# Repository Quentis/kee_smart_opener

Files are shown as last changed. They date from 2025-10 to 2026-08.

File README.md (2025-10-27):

# RAIL - SoC Empty

## Introduction

The Empty Example application is a boilerplate example which doesn't do anything
except initializes RAIL to support a Single PHY radio configuration. Also, this
example defines an empty radio event handler. These are the necessary parts what
every RAIL-based application requires.

## Prerequisites

The Empty Example application is supported on every EFR32 generations and
families that support proprietary software.

## Getting Started

Unlike the most of the available example applications in RAIL SDK, the Empty
Example does not define Command Line Interface nor does it support standard VCOM
printing or any other peripheral (LEDs/Button instances) by default.

Compile the project and download the application to a radio board. An unmodified
Empty Example shouldn't do any special:

- the radio is in idle state, while
- the MCU is running in an empty loop.

You might measure the current consumption (see the device's datasheet for the
expected active mode consumption) or debug the target device to make sure that
the example has been downloaded correctly to your device.

----

You can make the example energy friendly as simple as installing the `Power
Manager` component. Doing that the device will go to EM2 state after
initialization.

----

Adding basic packet TX/RX capabilities you might install the `Simple RAIL
Tx`/`Simple RAIL Rx` components.

## Peripherals

You can add LED and Button instances in the `Software Components` window.

To enable CLI interface you should install the `Command Line Interface (CLI)`
component. Make sure you satisfied the requirements by adding one of the `IO
Stream` dependency component, otherwise project generation will fail. If you are
working with a Silicon Labs development kit you should also ensure that the
Virtual COM port is enabled in the `Board Control` component in order to turn on
the serial bridge on the mainboard.

## Notes

> The application is designed in a way, that it can be run on an OS. You can add
> any RTOS support for this application in the `Software Components` window.
> Currently `MicriumOS` and `FreeRTOS` is supported.

## Conclusion

The `RAIL - SoC Empty` application sets up the absolute minimum to
start developing an application based on RAIL. If you want to test the basic
radio operation (packet transmission and reception) it is advised to create
`RAIL - SoC Simple TRX`.

## Resources

- [RAIL Tutorial
  Series](https://community.silabs.com/s/article/rail-tutorial-series?language=en_US):
  it is advised to read through the `Studio v5 series` first to familiarize the
  basics of packet transmission and reception.

## Report Bugs & Get Support

You are always encouraged and welcome to report any issues you found to us via
[Silicon Labs
Community](https://community.silabs.com/s/topic/0TO1M000000qHaKWAU/proprietary?language=en_US).

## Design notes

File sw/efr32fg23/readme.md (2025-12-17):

# RAIL - SoC Empty

## Introduction

The Empty Example application is a boilerplate example which doesn't do anything
except initializes RAIL to support a Single PHY radio configuration. Also, this
example defines an empty radio event handler. These are the necessary parts what
every RAIL-based application requires.

## Prerequisites

The Empty Example application is supported on every EFR32 generations and
families that support proprietary software.

## Getting Started

Unlike the most of the available example applications in RAIL SDK, the Empty
Example does not define Command Line Interface nor does it support standard VCOM
printing or any other peripheral (LEDs/Button instances) by default.

Compile the project and download the application to a radio board. An unmodified
Empty Example shouldn't do any special:

- the radio is in idle state, while
- the MCU is running in an empty loop.

You might measure the current consumption (see the device's datasheet for the
expected active mode consumption) or debug the target device to make sure that
the example has been downloaded correctly to your device.

----

You can make the example energy friendly as simple as installing the `Power
Manager` component. Doing that the device will go to EM2 state after
initialization.

----

Adding basic packet TX/RX capabilities you might install the `Simple RAIL
Tx`/`Simple RAIL Rx` components.

## Peripherals

You can add LED and Button instances in the `Software Components` window.

To enable CLI interface you should install the `Command Line Interface (CLI)`
component. Make sure you satisfied the requirements by adding one of the `IO
Stream` dependency component, otherwise project generation will fail. If you are
working with a Silicon Labs development kit you should also ensure that the
Virtual COM port is enabled in the `Board Control` component in order to turn on
the serial bridge on the mainboard.

## Notes

> The application is designed in a way, that it can be run on an OS. You can add
> any RTOS support for this application in the `Software Components` window.
> Currently `MicriumOS` and `FreeRTOS` is supported.

## Conclusion

The `RAIL - SoC Empty` application sets up the absolute minimum to
start developing an application based on RAIL. If you want to test the basic
radio operation (packet transmission and reception) it is advised to create
`RAIL - SoC Simple TRX`.

## Resources

- [RAIL Tutorial
  Series](https://community.silabs.com/s/article/rail-tutorial-series?language=en_US):
  it is advised to read through the `Studio v5 series` first to familiarize the
  basics of packet transmission and reception.

## Report Bugs & Get Support

You are always encouraged and welcome to report any issues you found to us via
[Silicon Labs
Community](https://community.silabs.com/s/topic/0TO1M000000qHaKWAU/proprietary?language=en_US).

## Startup

HFXO Startup Time: 178us

Reference: EFR32FG23 Wireless SoC Family Data Sheet

## Retrospective

I found these functional, non-functional, DX issues during development.

Some components requires power_manager component. I suppose because power manager provides some types for baremetal.
This is problematic because you may have a project which requires no power management then adding e.g. button press component the whole project starts to use power management however button press doesn't really need power manager for its functionality. This power management requirement is even more unnecessary for RTOS project in some cases because is_ok_to_sleep isn't needed in RTOS projects.

Missing comma in macro definition in app_log:
// ARRAY DUMP
#define app_log_array_dump_level(level, p_data, len, format) \
  app_log_array_dump_level_s(level,                          \
                             APP_LOG_ARRAY_DUMP_SEPARATOR    \
                             p_data,                         \
                             len,                            \
                             format)

## Measurements

**rtl_433-rtlsdr -R help**
[131]  Microchip HCS200/HCS300 KeeLoq Hopping Encoder based remotes

**rtl_433-rtlsdr -f 433.92M -Y level=-80 -s 2048k -g 0 -R 131 -A**

Detected OOK package    2025-12-17 14:02:14
_ _ _ _ _ _ _ _ _ _ _ _ _ _ _ _ _ _ _ _ _ _ _ _ _ _ _ _ _ _ _ _ _ _ _ _ _ _ _ _ _ _ _ _ _ _ _ _ _ _ _ _ _ _ _ _ _ _ _ _ _ _ _ _ _ _ _ _ _ _ _ _ _ _ _ _ _ _ _ _ _ _ _ _ _ _ _ _ _ _ _ _ _ _ _ _ _ _ _ _ _ _ _ _
time      : 2025-12-17 14:02:14
model     : Microchip-HCS200                       id        : 0095D63
Battery   : 1            Button    : 1             Learn mode: 0             Repeat    : 0             encrypted : 46029991
Analyzing pulses...
Total count:   78,  width: 92.01 ms             (188429 S)
Pulse width distribution:
 [ 0] count:   35,  width:  404 us [403;406]    ( 827 S)
 [ 1] count:   43,  width:  803 us [803;804]    (1645 S)
Gap width distribution:
 [ 0] count:   53,  width:  396 us [396;397]    ( 811 S)
 [ 1] count:    1,  width: 3997 us [3997;3997]  (8185 S)
 [ 2] count:   23,  width:  796 us [795;797]    (1630 S)
Pulse period distribution:
 [ 0] count:   11,  width:  800 us [799;801]    (1638 S)
 [ 1] count:    1,  width: 4400 us [4400;4400]  (9012 S)
 [ 2] count:   65,  width: 1200 us [1200;1200]  (2457 S)
Pulse timing distribution:
 [ 0] count:   88,  width:  399 us [396;406]    ( 817 S)
 [ 1] count:   66,  width:  801 us [795;804]    (1640 S)
 [ 2] count:    1,  width: 3997 us [3997;3997]  (8185 S)
 [ 3] count:    1,  width: 10000 us [10000;10000]       (20481 S)
Level estimates [high, low]:  15931,    472
RSSI: -0.1 dB SNR: 15.3 dB Noise: -15.4 dB
Frequency offsets [F1, F2]:   18614,      0     (+581.7 kHz, +0.0 kHz)
Guessing modulation: Pulse Width Modulation with multiple packets
view at https://triq.org/pdv/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
Attempting demodulation... short_width: 404, long_width: 803, reset_limit: 3997, sync_width: 0
Use a flex decoder with -X 'n=name,m=OOK_PWM,s=404,l=803,r=3997,g=798,t=160,y=0'
[pulse_slicer_pwm] Analyzer Device
codes     : {12}fff, {66}89994062c6ba90040

Detected OOK package    2025-12-17 14:04:35
_ _ _ _ _ _ _ _ _ _ _ _ _ _ _ _ _ _ _ _ _ _ _ _ _ _ _ _ _ _ _ _ _ _ _ _ _ _ _ _ _ _ _ _ _ _ _ _ _ _ _ _ _ _ _ _ _ _ _ _ _ _ _ _ _ _ _ _ _ _ _ _ _ _ _ _ _ _ _ _ _ _ _ _ _ _ _ _ _ _ _ _ _ _ _ _ _ _ _ _ _ _ _ _
time      : 2025-12-17 14:04:35
model     : Microchip-HCS200                       id        : 0095D63
Battery   : 1            Button    : 1             Learn mode: 0             Repeat    : 0             encrypted : 5DC7A207
Analyzing pulses...
Total count:   78,  width: 92.01 ms             (188428 S)
Pulse width distribution:
 [ 0] count:   40,  width:  403 us [403;405]    ( 826 S)
 [ 1] count:   38,  width:  804 us [803;805]    (1646 S)
Gap width distribution:
 [ 0] count:   48,  width:  396 us [396;397]    ( 811 S)
 [ 1] count:    1,  width: 3996 us [3996;3996]  (8184 S)
 [ 2] count:   28,  width:  796 us [795;797]    (1630 S)
Pulse period distribution:
 [ 0] count:   11,  width:  800 us [800;801]    (1638 S)
 [ 1] count:    1,  width: 4399 us [4399;4399]  (9010 S)
 [ 2] count:   65,  width: 1200 us [1199;1201]  (2457 S)
Pulse timing distribution:
 [ 0] count:   88,  width:  399 us [396;405]    ( 818 S)
 [ 1] count:   66,  width:  800 us [795;805]    (1639 S)
 [ 2] count:    1,  width: 3996 us [3996;3996]  (8184 S)
 [ 3] count:    1,  width: 10000 us [10000;10000]       (20481 S)
Level estimates [high, low]:  15726,    418
RSSI: -0.2 dB SNR: 15.8 dB Noise: -15.9 dB
Frequency offsets [F1, F2]:   17155,      0     (+536.1 kHz, +0.0 kHz)
Guessing modulation: Pulse Width Modulation with multiple packets
view at https://triq.org/pdv/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
Attempting demodulation... short_width: 403, long_width: 804, reset_limit: 3997, sync_width: 0
Use a flex decoder with -X 'n=name,m=OOK_PWM,s=403,l=804,r=3997,g=798,t=160,y=0'
[pulse_slicer_pwm] Analyzer Device
codes     : {12}fff, {66}e045e3bac6ba90040

Detected OOK package    2025-12-17 14:04:35
_ _ _ _ _ _ _ _ _ _ _ _ _ _ _ _ _ _ _ _ _ _ _ _ _ _ _ _ _ _ _ _ _ _ _ _ _ _ _ _ _ _ _ _ _ _ _ _ _ _ _ _ _ _ _ _ _ _ _ _ _ _ _ _ _ _ _ _ _ _ _ _ _ _ _ _ _ _ _ _ _ _ _ _ _ _ _ _ _ _ _ _ _ _ _ _ _ _ _ _ _ _ _ _
time      : 2025-12-17 14:04:35
model     : Microchip-HCS200                       id        : 0095D63
Battery   : 1            Button    : 1             Learn mode: 0             Repeat    : 1             encrypted : 5DC7A207
Analyzing pulses...
Total count:   78,  width: 91.61 ms             (187609 S)
Pulse width distribution:
 [ 0] count:   41,  width:  404 us [403;405]    ( 827 S)
 [ 1] count:   37,  width:  804 us [803;805]    (1646 S)
Gap width distribution:
 [ 0] count:   48,  width:  396 us [396;397]    ( 811 S)
 [ 1] count:    1,  width: 3996 us [3996;3996]  (8184 S)
 [ 2] count:   28,  width:  796 us [795;797]    (1630 S)
Pulse period distribution:
 [ 0] count:   11,  width:  800 us [800;801]    (1638 S)
 [ 1] count:    1,  width: 4400 us [4400;4400]  (9012 S)
 [ 2] count:   65,  width: 1200 us [1199;1201]  (2457 S)
Pulse timing distribution:
 [ 0] count:   89,  width:  399 us [396;405]    ( 818 S)
 [ 1] count:   65,  width:  800 us [795;805]    (1639 S)
 [ 2] count:    1,  width: 3996 us [3996;3996]  (8184 S)
 [ 3] count:    1,  width: 10000 us [10000;10000]       (20481 S)
Level estimates [high, low]:  15846,    479
RSSI: -0.1 dB SNR: 15.2 dB Noise: -15.3 dB
Frequency offsets [F1, F2]:   19862,      0     (+620.7 kHz, +0.0 kHz)
Guessing modulation: Pulse Width Modulation with multiple packets
view at https://triq.org/pdv/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
Attempting demodulation... short_width: 404, long_width: 804, reset_limit: 3997, sync_width: 0
Use a flex decoder with -X 'n=name,m=OOK_PWM,s=404,l=804,r=3997,g=797,t=160,y=0'
[pulse_slicer_pwm] Analyzer Device
codes     : {12}fff, {66}e045e3bac6ba90044

Detected OOK package    2025-12-17 14:04:35
_ _ _ _ _ _ _ _ _ _ _ _ _ _ _ _ _ _ _ _ _ _ _ _ _ _ _ _ _ _ _ _ _ _ _ _ _ _ _ _ _ _ _ _ _ _ _ _ _ _ _ _ _ _ _ _ _ _ _ _ _ _ _ _ _ _ _ _ _ _ _ _ _ _ _ _ _ _ _ _ _ _ _ _ _ _ _ _ _ _ _ _ _ _ _ _ _ _ _ _ _ _ _ _
time      : 2025-12-17 14:04:35
model     : Microchip-HCS200                       id        : 0095D63
Battery   : 1            Button    : 1             Learn mode: 0             Repeat    : 1             encrypted : 5DC7A207
Analyzing pulses...
Total count:   78,  width: 91.61 ms             (187610 S)
Pulse width distribution:
 [ 0] count:   41,  width:  404 us [403;405]    ( 827 S)
 [ 1] count:   37,  width:  804 us [803;805]    (1646 S)
Gap width distribution:
 [ 0] count:   48,  width:  396 us [396;397]    ( 811 S)
 [ 1] count:    1,  width: 3997 us [3997;3997]  (8185 S)
 [ 2] count:   28,  width:  796 us [795;797]    (1630 S)
Pulse period distribution:
 [ 0] count:   11,  width:  800 us [799;802]    (1638 S)
 [ 1] count:    1,  width: 4400 us [4400;4400]  (9012 S)
 [ 2] count:   65,  width: 1200 us [1199;1201]  (2457 S)
Pulse timing distribution:
 [ 0] count:   89,  width:  399 us [396;405]    ( 818 S)
 [ 1] count:   65,  width:  800 us [795;805]    (1639 S)
 [ 2] count:    1,  width: 3997 us [3997;3997]  (8185 S)
 [ 3] count:    1,  width: 10000 us [10000;10000]       (20481 S)
Level estimates [high, low]:  15923,    235
RSSI: -0.1 dB SNR: 18.3 dB Noise: -18.4 dB
Frequency offsets [F1, F2]:   19716,      0     (+616.1 kHz, +0.0 kHz)
Guessing modulation: Pulse Width Modulation with multiple packets
view at https://triq.org/pdv/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
Attempting demodulation... short_width: 404, long_width: 804, reset_limit: 3997, sync_width: 0
Use a flex decoder with -X 'n=name,m=OOK_PWM,s=404,l=804,r=3997,g=797,t=160,y=0'
[pulse_slicer_pwm] Analyzer Device
codes     : {12}fff, {66}e045e3bac6ba90044

Detected OOK package    2025-12-17 14:04:36
_ _ _ _ _ _ _ _ _ _ _ _ _ _ _ _ _ _ _ _ _ _ _ _ _ _ _ _ _ _ _ _ _ _ _ _ _ _ _ _ _ _ _ _ _ _ _ _ _ _ _ _ _ _ _ _ _ _ _ _ _ _ _ _ _ _ _ _ _ _ _ _ _ _ _ _ _ _ _ _ _ _ _ _ _ _ _ _ _ _ _ _ _ _ _ _ _ _ _ _ _ _ _ _
time      : 2025-12-17 14:04:36
model     : Microchip-HCS200                       id        : 0095D63
Battery   : 1            Button    : 1             Learn mode: 0             Repeat    : 1             encrypted : 5DC7A207
Analyzing pulses...
Total count:   78,  width: 91.61 ms             (187609 S)
Pulse width distribution:
 [ 0] count:   41,  width:  403 us [403;406]    ( 826 S)
 [ 1] count:   37,  width:  803 us [803;805]    (1645 S)
Gap width distribution:
 [ 0] count:   48,  width:  396 us [396;397]    ( 811 S)
 [ 1] count:    1,  width: 3997 us [3997;3997]  (8185 S)
 [ 2] count:   28,  width:  796 us [795;797]    (1630 S)
Pulse period distribution:
 [ 0] count:   11,  width:  800 us [800;802]    (1638 S)
 [ 1] count:    1,  width: 4400 us [4400;4400]  (9011 S)
 [ 2] count:   65,  width: 1200 us [1199;1201]  (2457 S)
Pulse timing distribution:
 [ 0] count:   89,  width:  399 us [396;406]    ( 818 S)
 [ 1] count:   65,  width:  800 us [795;805]    (1639 S)
 [ 2] count:    1,  width: 3997 us [3997;3997]  (8185 S)
 [ 3] count:    1,  width: 10000 us [10000;10000]       (20481 S)
Level estimates [high, low]:  15648,     77
RSSI: -0.2 dB SNR: 23.1 dB Noise: -23.3 dB
Frequency offsets [F1, F2]:   17343,      0     (+542.0 kHz, +0.0 kHz)
Guessing modulation: Pulse Width Modulation with multiple packets
view at https://triq.org/pdv/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
Attempting demodulation... short_width: 403, long_width: 803, reset_limit: 3997, sync_width: 0
Use a flex decoder with -X 'n=name,m=OOK_PWM,s=403,l=803,r=3997,g=797,t=160,y=0'
[pulse_slicer_pwm] Analyzer Device
codes     : {12}fff, {66}e045e3bac6ba90044

Detected OOK package    2025-12-17 14:04:36
_ _ _ _ _ _ _ _ _ _ _ _ _ _ _ _ _ _ _ _ _ _ _ _ _ _ _ _ _ _ _ _ _ _ _ _ _ _ _ _ _ _ _ _ _ _ _ _ _ _ _ _ _ _ _ _ _ _ _ _ _ _ _ _ _ _ _ _ _ _ _ _ _ _ _ _ _ _ _ _ _ _ _ _ _ _ _ _ _ _ _ _ _ _ _ _ _ _ _ _ _ _ _ _
time      : 2025-12-17 14:04:36
model     : Microchip-HCS200                       id        : 0095D63
Battery   : 1            Button    : 1             Learn mode: 0             Repeat    : 1             encrypted : 5DC7A207
Analyzing pulses...
Total count:   78,  width: 91.61 ms             (187608 S)
Pulse width distribution:
 [ 0] count:   41,  width:  403 us [402;406]    ( 826 S)
 [ 1] count:   37,  width:  803 us [802;804]    (1645 S)
Gap width distribution:
 [ 0] count:   48,  width:  396 us [396;397]    ( 812 S)
 [ 1] count:    1,  width: 3997 us [3997;3997]  (8186 S)
 [ 2] count:   28,  width:  796 us [795;797]    (1631 S)
Pulse period distribution:
 [ 0] count:   11,  width:  800 us [800;802]    (1638 S)
 [ 1] count:    1,  width: 4400 us [4400;4400]  (9011 S)
 [ 2] count:   65,  width: 1200 us [1199;1201]  (2457 S)
Pulse timing distribution:
 [ 0] count:   89,  width:  399 us [396;406]    ( 818 S)
 [ 1] count:   65,  width:  800 us [795;804]    (1639 S)
 [ 2] count:    1,  width: 3997 us [3997;3997]  (8186 S)
 [ 3] count:    1,  width: 10000 us [10000;10000]       (20481 S)
Level estimates [high, low]:  15731,     52
RSSI: -0.2 dB SNR: 24.8 dB Noise: -25.0 dB
Frequency offsets [F1, F2]:   17112,      0     (+534.8 kHz, +0.0 kHz)
Guessing modulation: Pulse Width Modulation with multiple packets
view at https://triq.org/pdv/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
Attempting demodulation... short_width: 403, long_width: 803, reset_limit: 3998, sync_width: 0
Use a flex decoder with -X 'n=name,m=OOK_PWM,s=403,l=803,r=3998,g=798,t=160,y=0'
[pulse_slicer_pwm] Analyzer Device
codes     : {12}fff, {66}e045e3bac6ba90044

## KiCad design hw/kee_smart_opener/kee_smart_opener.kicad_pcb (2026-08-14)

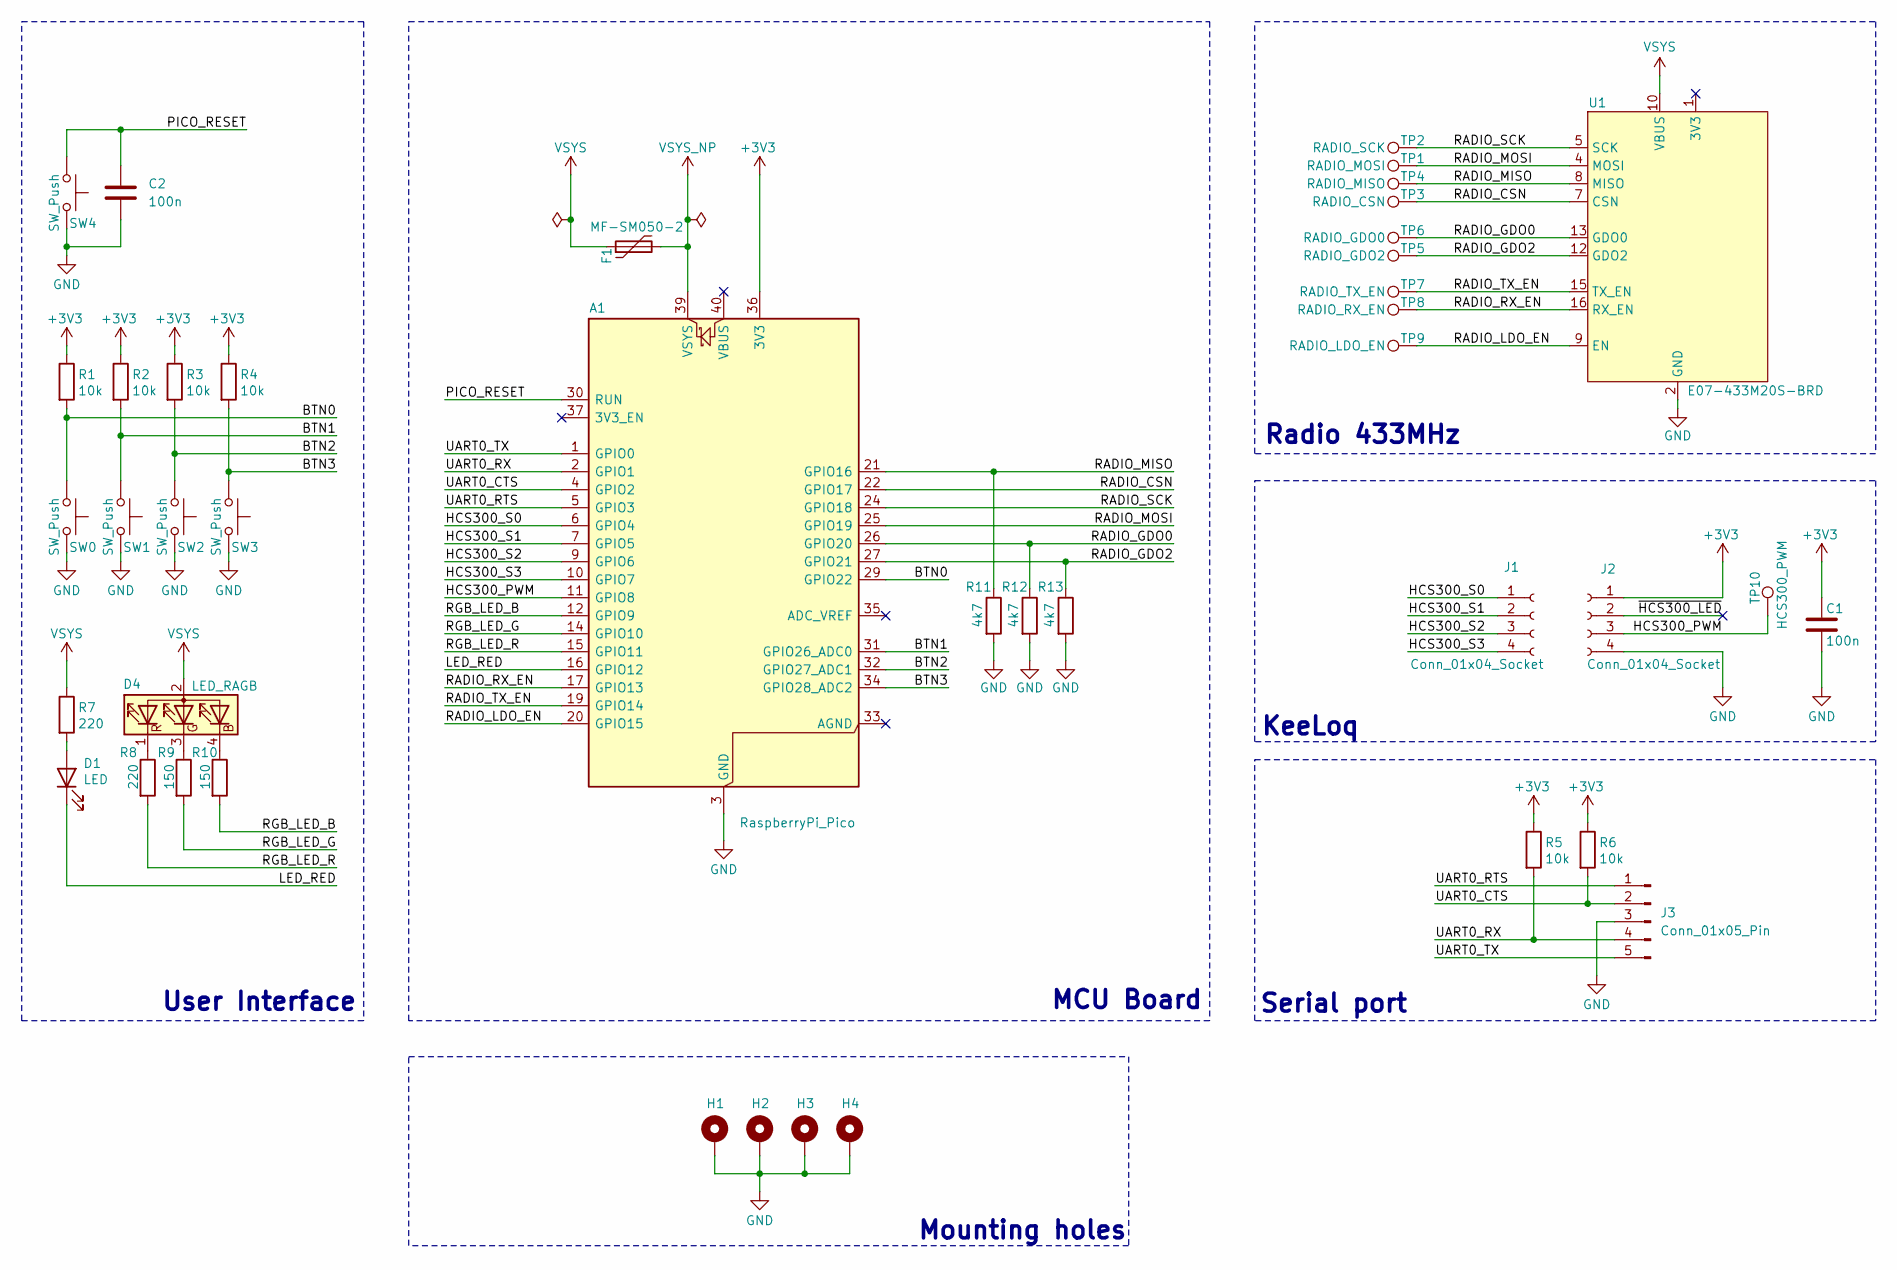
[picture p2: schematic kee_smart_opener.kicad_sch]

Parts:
A1: RaspberryPi_Pico; RaspberryPi_Pico_Common_THT
C1, C2: 100n; C_0603_1608Metric_Pad1.08x0.95mm_HandSolder
D1: LED; LED_D5.0mm
D4: LED_RAGB; LED_D5.0mm-4_RGB
F1: MF-SM050-2; Fuse_Bourns_MF-SM_7.98x5.44mm
H1, H2, H3, H4: MountingHole_Pad; MountingHole_3.5mm_Pad_Via
J1, J2: Conn_01x04_Socket; PinSocket_1x04_P2.54mm_Vertical
J3: Conn_01x05_Pin; PinHeader_1x05_P2.54mm_Horizontal
R1, R2, R3, R4, R5, R6: 10k; R_0603_1608Metric_Pad0.98x0.95mm_HandSolder
R7, R8: 220; R_0603_1608Metric_Pad0.98x0.95mm_HandSolder
R9, R10: 150; R_0603_1608Metric_Pad0.98x0.95mm_HandSolder
R11, R12, R13: 4k7; R_0603_1608Metric_Pad0.98x0.95mm_HandSolder
SW0, SW1, SW2, SW3, SW4: SW_Push; SW_B3F-3100
TP1: RADIO_MOSI; TestPoint_Pad_D1.5mm
TP2: RADIO_SCK; TestPoint_Pad_D1.5mm
TP3: RADIO_CSN; TestPoint_Pad_D1.5mm
TP4: RADIO_MISO; TestPoint_Pad_D1.5mm
TP5: RADIO_GDO2; TestPoint_Pad_D1.5mm
TP6: RADIO_GDO0; TestPoint_Pad_D1.5mm
TP7: RADIO_TX_EN; TestPoint_Pad_D1.5mm
TP8: RADIO_RX_EN; TestPoint_Pad_D1.5mm
TP9: RADIO_LDO_EN; TestPoint_Pad_D1.5mm
TP10: HCS300_PWM; TestPoint_Pad_D1.5mm
U1: E07-433M20S-BRD

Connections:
+3V3: A1.36 (3V3), C1.1, J2.1, R1.1, R2.1, R3.1, R4.1, R5.1, R6.1
/BTN0: A1.29 (GPIO22), R1.2, SW0.2
/BTN1: A1.31 (GPIO26_ADC0), R2.2, SW1.2
/BTN2: A1.32 (GPIO27_ADC1), R3.2, SW2.2
/BTN3: A1.34 (GPIO28_ADC2), R4.2, SW3.2
/HCS300_PWM: A1.11 (GPIO8), J2.3, TP10.1 (1_1)
/HCS300_S0: A1.6 (GPIO4), J1.1
/HCS300_S1: A1.7 (GPIO5), J1.2
/HCS300_S2: A1.9 (GPIO6), J1.3
/HCS300_S3: A1.10 (GPIO7), J1.4
/LED_RED: A1.16 (GPIO12), D1.1 (K)
/PICO_RESET: A1.30 (RUN), C2.1, SW4.2
/RADIO_CSN: A1.22 (GPIO17), TP3.1 (1_1), U1.7 (CSN)
/RADIO_GDO0: A1.26 (GPIO20), R12.1, TP6.1 (1_1), U1.13 (GDO0)
/RADIO_GDO2: A1.27 (GPIO21), R13.1, TP5.1 (1_1), U1.12 (GDO2)
/RADIO_LDO_EN: A1.20 (GPIO15), TP9.1 (1_1), U1.9 (EN)
/RADIO_MISO: A1.21 (GPIO16), R11.1, TP4.1 (1_1), U1.8 (MISO)
/RADIO_MOSI: A1.25 (GPIO19), TP1.1 (1_1), U1.4 (MOSI)
/RADIO_RX_EN: A1.17 (GPIO13), TP8.1 (1_1), U1.16 (RX_EN)
/RADIO_SCK: A1.24 (GPIO18), TP2.1 (1_1), U1.5 (SCK)
/RADIO_TX_EN: A1.19 (GPIO14), TP7.1 (1_1), U1.15 (TX_EN)
/RGB_LED_B: A1.12 (GPIO9), R10.2
/RGB_LED_G: A1.14 (GPIO10), R9.2
/RGB_LED_R: A1.15 (GPIO11), R8.2
/UART0_CTS: A1.4 (GPIO2), J3.2, R6.2
/UART0_RTS: A1.5 (GPIO3), J3.1
/UART0_RX: A1.2 (GPIO1), J3.4, R5.2
/UART0_TX: A1.1 (GPIO0), J3.5
/~HCS300_LED: J2.2
GND: A1.3 (GND), A1.8 (GND), A1.13 (GND), A1.18 (GND), A1.23 (GND), A1.28 (GND), A1.38 (GND), C1.2, C2.2, H1.1 (1_1), H2.1 (1_1), H3.1 (1_1), H4.1 (1_1), J2.4, J3.3, R11.2, R12.2, R13.2, SW0.1, SW1.1, SW2.1, SW3.1, SW4.1, U1.2 (GND), U1.3 (GND), U1.6 (GND), U1.11 (GND), U1.14 (GND)
unnamed: D1.2 (A), R7.2
unnamed: D4.4 (BK), R10.1
unnamed: D4.3 (GK), R9.1
unnamed: D4.1 (RK), R8.1
VSYS: D4.2 (A), F1.1, R7.1, U1.10 (VBUS)
VSYS_NP: A1.39 (VSYS), F1.2

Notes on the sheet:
Serial port
Radio 433MHz
User Interface
KeeLoq
Mounting holes
MCU Board

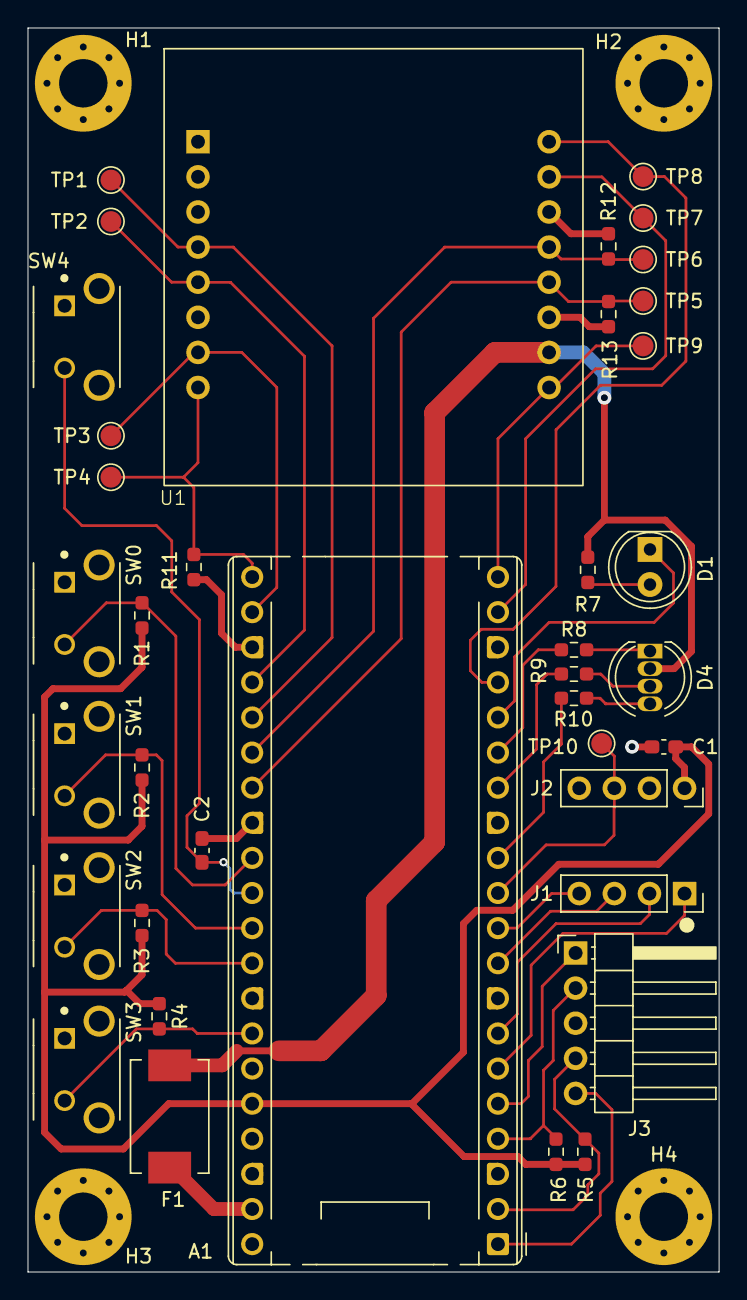
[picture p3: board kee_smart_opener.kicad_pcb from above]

Board: 2 copper layers, 50.0 x 90.0 mm, 42 parts (0 on the bottom side), 35 nets.

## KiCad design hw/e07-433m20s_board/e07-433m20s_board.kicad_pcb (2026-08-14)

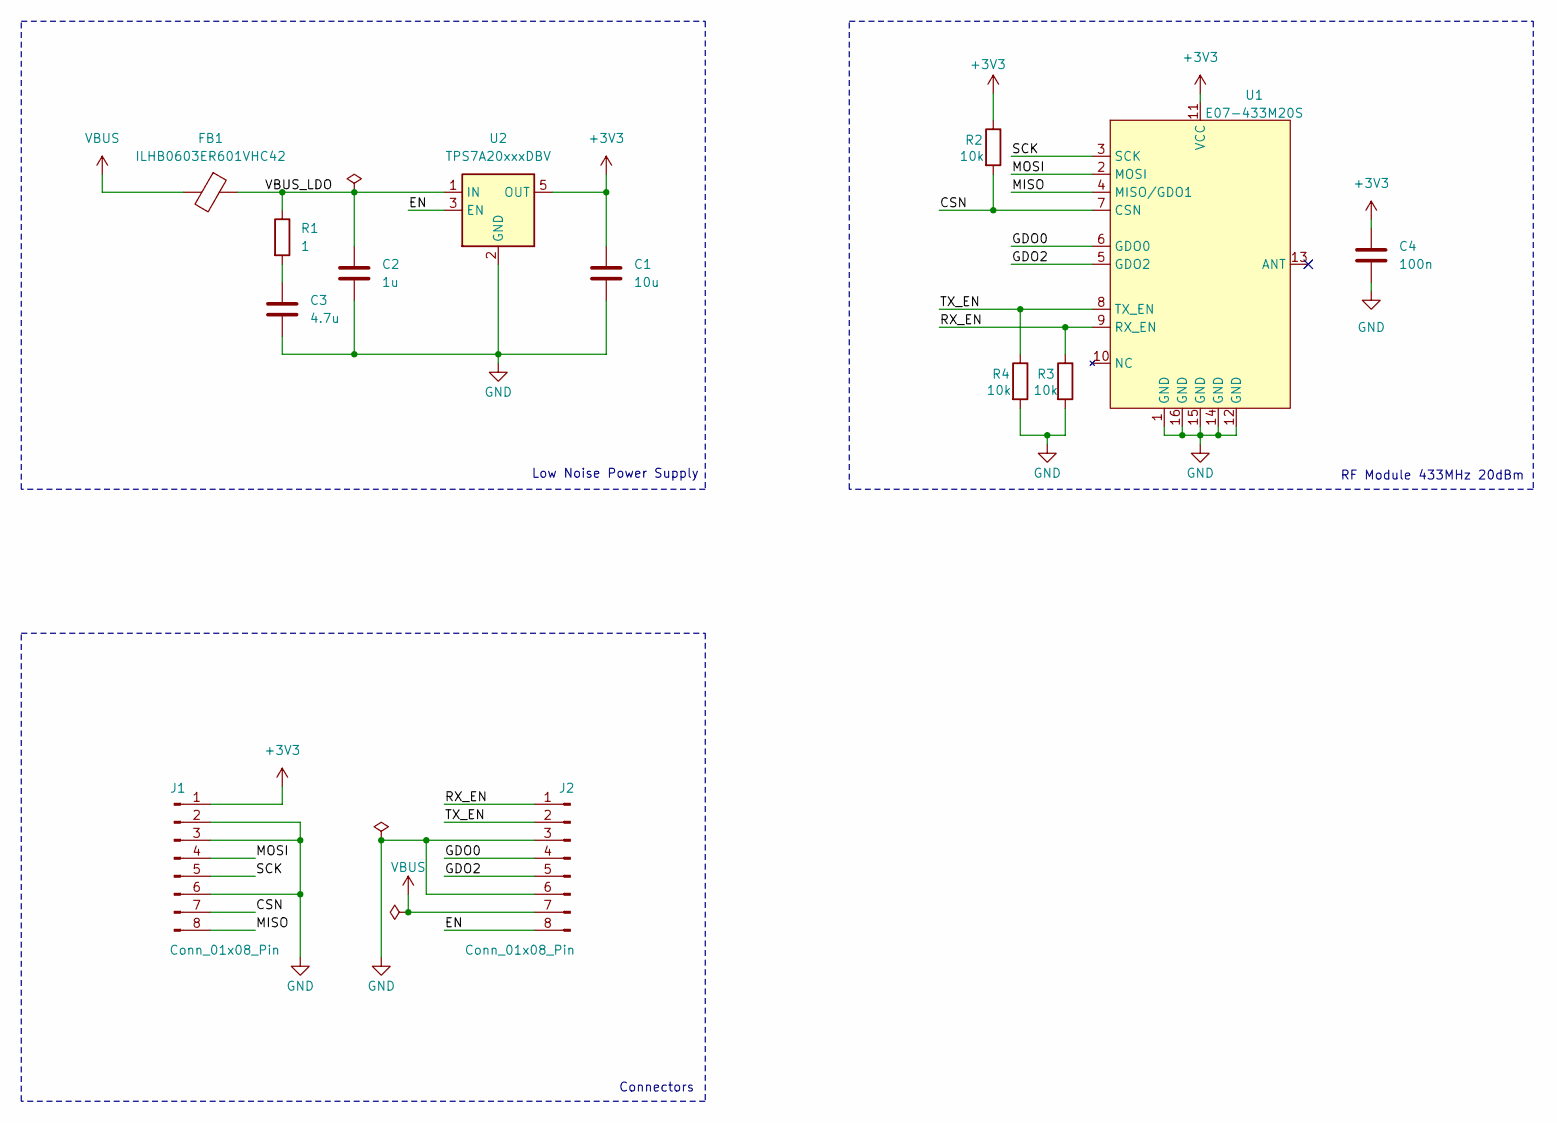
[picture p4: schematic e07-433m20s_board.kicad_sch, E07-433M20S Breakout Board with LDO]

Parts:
C1: 10u; C_0805_2012Metric_Pad1.18x1.45mm_HandSolder
C2: 1u; C_0603_1608Metric_Pad1.08x0.95mm_HandSolder
C3: 4.7u; C_0805_2012Metric_Pad1.18x1.45mm_HandSolder
C4: 100n; C_0603_1608Metric_Pad1.08x0.95mm_HandSolder
FB1: ILHB0603ER601VHC42; L_0603_1608Metric
J1, J2: Conn_01x08_Pin; PinHeader_1x08_P2.54mm_Vertical
R1: 1; R_0603_1608Metric_Pad0.98x0.95mm_HandSolder
R2, R3, R4: 10k; R_0603_1608Metric_Pad0.98x0.95mm_HandSolder
U1: E07-433M20S
U2: TPS7A20xxxDBV; SOT-23-5

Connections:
+3V3: C1.1, C4.1, J1.1, R2.1, U1.11 (VCC), U2.5 (OUT)
/CSN: J1.7, R2.2, U1.7 (CSN)
/EN: J2.8, U2.3 (EN)
/GDO0: J2.4, U1.6 (GDO0)
/GDO2: J2.5, U1.5 (GDO2)
/MISO: J1.8, U1.4 (MISO/GDO1)
/MOSI: J1.4, U1.2 (MOSI)
/RX_EN: J2.1, R3.1, U1.9 (RX_EN)
/SCK: J1.5, U1.3 (SCK)
/TX_EN: J2.2, R4.1, U1.8 (TX_EN)
/VBUS_LDO: C2.1, FB1.1, R1.1, U2.1 (IN)
GND: C1.2, C2.2, C3.2, C4.2, J1.2, J1.3, J1.6, J2.3, J2.6, R3.2, R4.2, U1.1 (GND), U1.12 (GND), U1.14 (GND), U1.15 (GND), U1.16 (GND), U2.2 (GND)
unnamed: C3.1, R1.2
VBUS: FB1.2, J2.7

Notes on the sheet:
Connectors
RF Module 433MHz 20dBm
Low Noise Power Supply

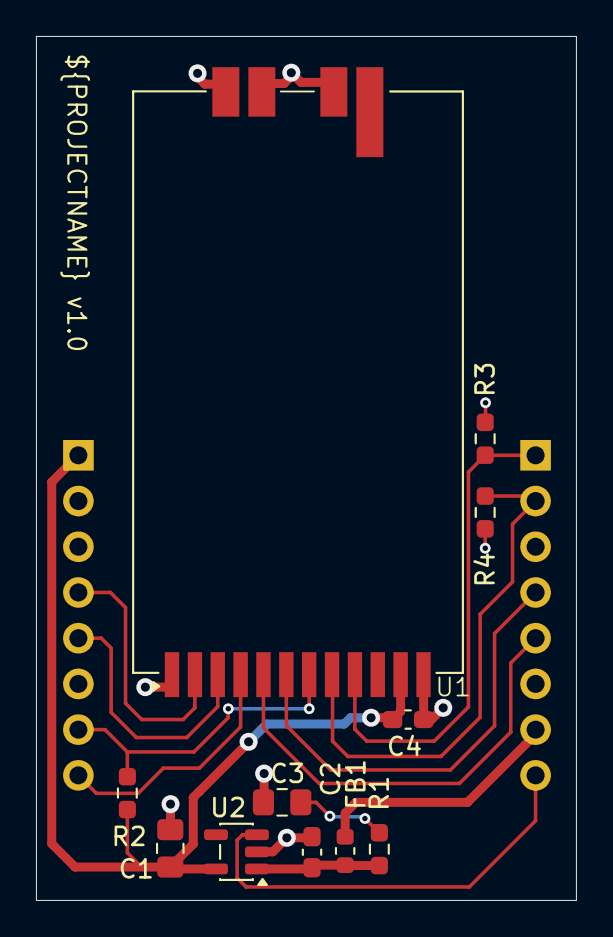
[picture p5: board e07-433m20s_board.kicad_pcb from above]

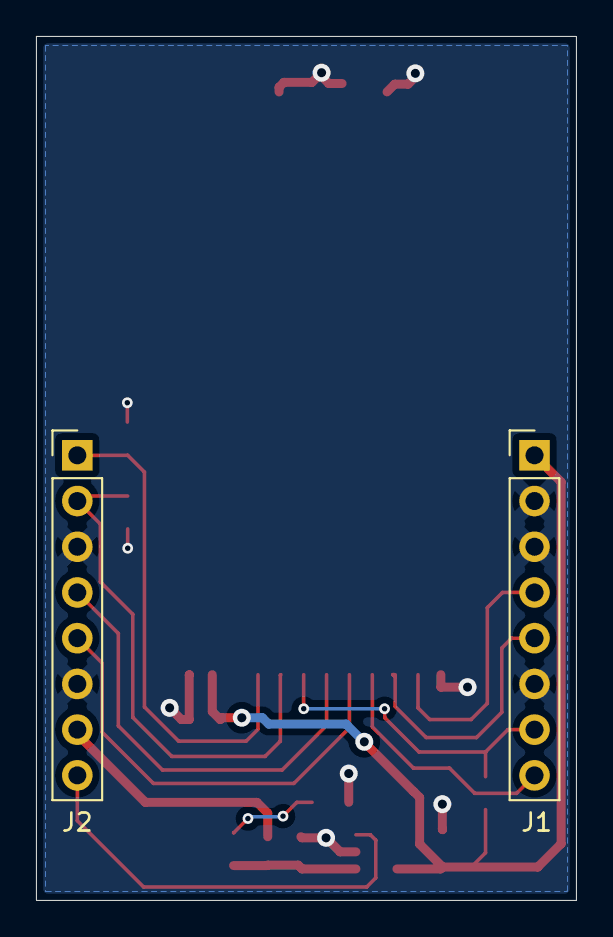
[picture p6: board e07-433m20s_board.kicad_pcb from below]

Board: 2 copper layers, 30.0 x 48.0 mm, 13 parts (2 on the bottom side), 14 nets.

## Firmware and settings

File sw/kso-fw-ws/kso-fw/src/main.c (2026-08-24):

/*
 * Copyright (c) 2012-2014 Wind River Systems, Inc.
 *
 * SPDX-License-Identifier: Apache-2.0
 */

#include <stdio.h>
#include <zephyr/kernel.h>
#include <zephyr/device.h>
#include <zephyr/input/input.h>
#include <zephyr/drivers/pwm.h>
#include <zephyr/drivers/gpio.h>
#include <zephyr/toolchain.h>

static const struct pwm_dt_spec pwm_led_red = PWM_DT_SPEC_GET(DT_NODELABEL(pwm_led_red));
static const struct pwm_dt_spec pwm_led_green = PWM_DT_SPEC_GET(DT_NODELABEL(pwm_led_green));
static const struct pwm_dt_spec pwm_led_blue = PWM_DT_SPEC_GET(DT_NODELABEL(pwm_led_blue));

static const struct gpio_dt_spec led_error = GPIO_DT_SPEC_GET(DT_NODELABEL(led_error), gpios);

static const struct gpio_dt_spec button_0 = GPIO_DT_SPEC_GET(DT_NODELABEL(button_0), gpios);
static const struct gpio_dt_spec button_1 = GPIO_DT_SPEC_GET(DT_NODELABEL(button_1), gpios);
static const struct gpio_dt_spec button_2 = GPIO_DT_SPEC_GET(DT_NODELABEL(button_2), gpios);
static const struct gpio_dt_spec button_3 = GPIO_DT_SPEC_GET(DT_NODELABEL(button_3), gpios);

static void button_input_cb(struct input_event *evt, void *user_data) {
	ARG_UNUSED(user_data);

	if (evt->sync == 0) {
		return;
	}

	printf("Button %d %s at %" PRIu32 "\n",
	       evt->code,
	       evt->value ? "pressed" : "released",
	       k_uptime_get_32());
}

INPUT_CALLBACK_DEFINE(NULL, button_input_cb, NULL);

static void led_test(void) {
	pwm_set_pulse_dt(&pwm_led_red, 0);
	pwm_set_pulse_dt(&pwm_led_green, 0);
	pwm_set_pulse_dt(&pwm_led_blue, 0);
	gpio_pin_set_dt(&led_error, 1);
	k_msleep(1000);
	gpio_pin_set_dt(&led_error, 0);
	
	for (int i = 0; i <= 100; i++) {
		k_msleep(10);
		pwm_set_pulse_dt(&pwm_led_red, PWM_USEC(i * 10));
	}
	pwm_set_pulse_dt(&pwm_led_red, 0);
	k_msleep(1000);

	for (int i = 0; i <= 100; i++) {
		k_msleep(10);
		pwm_set_pulse_dt(&pwm_led_green, PWM_USEC(i * 10));
	}
	pwm_set_pulse_dt(&pwm_led_green, 0);
	k_msleep(1000);

	for (int i = 0; i <= 100; i++) {
		k_msleep(10);
		pwm_set_pulse_dt(&pwm_led_blue, PWM_USEC(i * 10));
	}
	pwm_set_pulse_dt(&pwm_led_blue, 0);
	k_msleep(1000);
}

int main(void)
{
	printf("Hello World! %s\n", CONFIG_BOARD_TARGET);

	if (!device_is_ready(led_error.port)) {
		printf("Error: LED device %s is not ready\n", led_error.port->name);
		return 0;
	}

	if (!pwm_is_ready_dt(&pwm_led_red)) {
		printf("Error: PWM device %s is not ready\n",
		       pwm_led_red.dev->name);
		return 0;
	}
	if (!pwm_is_ready_dt(&pwm_led_green)) {
		printf("Error: PWM device %s is not ready\n",
		       pwm_led_green.dev->name);
		return 0;
	}
	if (!pwm_is_ready_dt(&pwm_led_blue)) {
		printf("Error: PWM device %s is not ready\n",
		       pwm_led_blue.dev->name);
		return 0;
	}
	int ret = gpio_pin_configure_dt(&led_error, GPIO_OUTPUT_ACTIVE);
	if (ret < 0) {
		return 0;
	}

	if (!device_is_ready(button_0.port)) {
		printk("Error: button device %s is not ready\n", button_0.port->name);
    		return -1;
	}

	if (!device_is_ready(button_1.port)) {
		printk("Error: button device %s is not ready\n", button_1.port->name);
    		return -1;
	}

	if (!device_is_ready(button_2.port)) {
		printk("Error: button device %s is not ready\n", button_2.port->name);
    		return -1;
	}

	if (!device_is_ready(button_3.port)) {
		printk("Error: button device %s is not ready\n", button_3.port->name);
    		return -1;
	}

	// Turn off all LEDs
	pwm_set_pulse_dt(&pwm_led_red, 0);
	pwm_set_pulse_dt(&pwm_led_green, 0);
	pwm_set_pulse_dt(&pwm_led_blue, 0);
	gpio_pin_set_dt(&led_error, 0);

	while(1) {
		k_msleep(1000);
	}

	return 0;
}

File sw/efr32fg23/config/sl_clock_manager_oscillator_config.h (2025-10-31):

/***************************************************************************//**
 * @file
 * @brief Clock Manager - Oscillators configuration file.
 *******************************************************************************
 * # License
 * <b>Copyright 2025 Silicon Laboratories Inc. www.silabs.com</b>
 *******************************************************************************
 *
 * SPDX-License-Identifier: Zlib
 *
 * The licensor of this software is Silicon Laboratories Inc.
 *
 * This software is provided 'as-is', without any express or implied
 * warranty. In no event will the authors be held liable for any damages
 * arising from the use of this software.
 *
 * Permission is granted to anyone to use this software for any purpose,
 * including commercial applications, and to alter it and redistribute it
 * freely, subject to the following restrictions:
 *
 * 1. The origin of this software must not be misrepresented; you must not
 *    claim that you wrote the original software. If you use this software
 *    in a product, an acknowledgment in the product documentation would be
 *    appreciated but is not required.
 * 2. Altered source versions must be plainly marked as such, and must not be
 *    misrepresented as being the original software.
 * 3. This notice may not be removed or altered from any source distribution.
 *
 ******************************************************************************/

 #ifndef SL_CLOCK_MANAGER_OSCILLATOR_CONFIG_H
#define SL_CLOCK_MANAGER_OSCILLATOR_CONFIG_H

#if defined(SL_COMPONENT_CATALOG_PRESENT)
#include "sl_component_catalog.h"

#endif

// Internal Defines: DO NOT MODIFY
#define SL_CLOCK_MANAGER_HFXO_EN_ENABLE     1
#define SL_CLOCK_MANAGER_HFXO_EN_DISABLE    0

#if defined(SL_CATALOG_RAIL_LIB_PRESENT)
#define SL_CLOCK_MANAGER_HFXO_EN_AUTO       SL_CLOCK_MANAGER_HFXO_EN_ENABLE
#else
#define SL_CLOCK_MANAGER_HFXO_EN_AUTO       SL_CLOCK_MANAGER_HFXO_EN_DISABLE
#endif

// <<< Use Configuration Wizard in Context Menu >>>

// <h> Oscillators Settings

// <h> HFXO Settings (if High Frequency crystal is used)

// <o SL_CLOCK_MANAGER_HFXO_EN> Enable
// <i> Enable to configure HFXO
// <i> AUTO enables HFXO if a radio is used
// <SL_CLOCK_MANAGER_HFXO_EN_AUTO=> AUTO
// <SL_CLOCK_MANAGER_HFXO_EN_ENABLE=> ENABLE
// <SL_CLOCK_MANAGER_HFXO_EN_DISABLE=> DISABLE
// <d> SL_CLOCK_MANAGER_HFXO_EN_AUTO
#ifndef SL_CLOCK_MANAGER_HFXO_EN
#define SL_CLOCK_MANAGER_HFXO_EN    SL_CLOCK_MANAGER_HFXO_EN_ENABLE
#endif

// <o SL_CLOCK_MANAGER_HFXO_MODE> Mode
// <i>
// <HFXO_CFG_MODE_XTAL=> XTAL
// <HFXO_CFG_MODE_EXTCLK=> EXTCLK
// <HFXO_CFG_MODE_EXTCLKPKDET=> EXTCLKPKDET
// <d> HFXO_CFG_MODE_XTAL
#ifndef SL_CLOCK_MANAGER_HFXO_MODE
#define SL_CLOCK_MANAGER_HFXO_MODE    HFXO_CFG_MODE_XTAL
#endif

// <o SL_CLOCK_MANAGER_HFXO_FREQ> Frequency in Hz <38000000-40000000>
// <d> 39000000
#ifndef SL_CLOCK_MANAGER_HFXO_FREQ
#define SL_CLOCK_MANAGER_HFXO_FREQ    39000000
#endif

// <o SL_CLOCK_MANAGER_HFXO_CTUNE> CTUNE <0-255>
// <d> 140
#ifndef SL_CLOCK_MANAGER_HFXO_CTUNE
#define SL_CLOCK_MANAGER_HFXO_CTUNE    118
#endif

// <o SL_CLOCK_MANAGER_HFXO_PRECISION> Precision in PPM <0-65535>
// <d> 50
#ifndef SL_CLOCK_MANAGER_HFXO_PRECISION
#define SL_CLOCK_MANAGER_HFXO_PRECISION    50
#endif

// <q SL_CLOCK_MANAGER_CTUNE_MFG_HFXO_EN> CTUNE HXFO manufacturing
// <i> Enable to use CTUNE HFXO manufacturing value for calibration
// <d> 1
#ifndef SL_CLOCK_MANAGER_CTUNE_MFG_HFXO_EN
#define SL_CLOCK_MANAGER_CTUNE_MFG_HFXO_EN    1
#endif

// <e SL_CLOCK_MANAGER_HFXO_CRYSTAL_SHARING_EN> HFXO crystal sharing feature
// <i> Enable to configure HFXO crystal sharing leader or follower
#ifndef SL_CLOCK_MANAGER_HFXO_CRYSTAL_SHARING_EN
#define SL_CLOCK_MANAGER_HFXO_CRYSTAL_SHARING_EN    0
#endif

// <e SL_CLOCK_MANAGER_HFXO_CRYSTAL_SHARING_LEADER_EN> Crystal sharing leader
// <i> Enable to configure HFXO crystal sharing leader
#ifndef SL_CLOCK_MANAGER_HFXO_CRYSTAL_SHARING_LEADER_EN
#define SL_CLOCK_MANAGER_HFXO_CRYSTAL_SHARING_LEADER_EN    0
#endif

// <e SL_CLOCK_MANAGER_HFXO_CRYSTAL_SHARING_LEADER_MIN_STARTUP_DELAY_EN> Crystal sharing leader minimum startup delay
// <i> If enabled, BUFOUT does not start until timeout set in
// <i> SL_CLOCK_MANAGER_HFXO_CRYSTAL_SHARING_LEADER_TIMEOUT_STARTUP expires.
// <i> This prevents waste of power if BUFOUT is ready too early.
// <d> 1
#ifndef SL_CLOCK_MANAGER_HFXO_CRYSTAL_SHARING_LEADER_MIN_STARTUP_DELAY_EN
#define SL_CLOCK_MANAGER_HFXO_CRYSTAL_SHARING_LEADER_MIN_STARTUP_DELAY_EN    1
#endif
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

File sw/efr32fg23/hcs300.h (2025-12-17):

#ifndef HCS300_H
#define HCS300_H

#include <stdint.h>
#include <stdbool.h>

#include "sl_status.h"

// HCS300 protocol parameters
// All timings values are integer multiples of TE.
// TE is configurable between: 100us, 200us, 400us.
// Packet:
//   - Preamble: 23 TE (12 sync pulses) - 50% duty cycle
//   - Header: 10 TE gap
//   - Data: 66 bits -> 1 bit is 3 TE (PWM modulated)
//     - 0 bit: 2 TE high, 1 TE low
//     - 1 bit: 1 TE high, 2 TE low

// 50% duty cycle preamble
#define HCS300_PREAMBLE_TE            23

// Gap between preamble and data
#define HCS300_HEADER_GAP_TE          10

// Serial number, button code, VLOW and RPT bits
#define HCS300_FIXED_BITS             34
#define HCS300_ENCRYPTED_BITS         32
#define HCS300_BIT_TE                  3

// Data portion of code word (66 bits)
#define HCS300_DATA_BITS              (HCS300_ENCRYPTED_BITS + HCS300_FIXED_BITS)

// Total code word data length in TE units (each bit is encoded in 3 TE - PWM modulated)
#define HCS300_DATA_BITS_TE         (HCS300_DATA_BITS * HCS300_BIT_TE)

#define HCS300_CODEWORD_DATA_BYTES  ((HCS300_DATA_BITS_TE + 7) >> 3)
#define HCS300_CODEWORD_BYTES       ((HCS300_PREAMBLE_TE    \
                                    + HCS300_HEADER_GAP_TE  \
                                    + HCS300_DATA_BITS_TE + 7) >> 3)

// Button status getter macros
#define HCS300_BTN_STATUS_S0(btn_status)  ((btn_status) & HCS300_S0)
#define HCS300_BTN_STATUS_S1(btn_status)  ((btn_status) & HCS300_S1)
#define HCS300_BTN_STATUS_S2(btn_status)  ((btn_status) & HCS300_S2)
#define HCS300_BTN_STATUS_S3(btn_status)  ((btn_status) & HCS300_S3)

// The button inputs of HCS300 chip shall be activated to receive pwm signal.
typedef enum hcs300_sw_id {
  HCS300_S0 = 0x1,
  HCS300_S1 = 0x2,
  HCS300_S2 = 0x4,
  HCS300_S3 = 0x8,
} hcs300_sw_id_t;

sl_status_t hcs300_init(void);
sl_status_t hcs300_deinit(void);
sl_status_t hcs300_activate(hcs300_sw_id_t sw, bool repeat);
void hcs300_step(void);

void hcs300_proceed_cb(void);

sl_status_t hcs300_create_codeword(uint16_t hcs300_id,
                                   uint8_t *codeword,
                                   uint16_t *codeword_len,
                                   bool rpt,
                                   bool vlow,
                                   uint8_t btn_status,
                                   uint32_t serial,
                                   uint32_t encrypted);

sl_status_t hcs300_create_codeword_data(uint16_t hcs300_id,
                                        uint8_t *codeword,
                                        uint16_t *codeword_len,
                                        bool rpt,
                                        bool vlow,
                                        uint8_t btn_status,
                                        uint32_t serial,
                                        uint32_t encrypted);

void hcs300_on_rx_packet(uint16_t hcs300_id,
                         bool rpt,
                         bool vlow,
                         uint8_t btn_status,
                         uint32_t serial,
                         uint32_t encrypted);
#endif // HCS300_H

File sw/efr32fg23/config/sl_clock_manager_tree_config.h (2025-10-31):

/***************************************************************************//**
 * @file
 * @brief Clock Manager - Clock Tree configuration file.
 *******************************************************************************
 * # License
 * <b>Copyright 2025 Silicon Laboratories Inc. www.silabs.com</b>
 *******************************************************************************
 *
 * SPDX-License-Identifier: Zlib
 *
 * The licensor of this software is Silicon Laboratories Inc.
 *
 * This software is provided 'as-is', without any express or implied
 * warranty. In no event will the authors be held liable for any damages
 * arising from the use of this software.
 *
 * Permission is granted to anyone to use this software for any purpose,
 * including commercial applications, and to alter it and redistribute it
 * freely, subject to the following restrictions:
 *
 * 1. The origin of this software must not be misrepresented; you must not
 *    claim that you wrote the original software. If you use this software
 *    in a product, an acknowledgment in the product documentation would be
 *    appreciated but is not required.
 * 2. Altered source versions must be plainly marked as such, and must not be
 *    misrepresented as being the original software.
 * 3. This notice may not be removed or altered from any source distribution.
 *
 ******************************************************************************/

#ifndef SL_CLOCK_MANAGER_TREE_CONFIG_H
#define SL_CLOCK_MANAGER_TREE_CONFIG_H

#if defined(SL_COMPONENT_CATALOG_PRESENT)
#include "sl_component_catalog.h"

#endif

// Internal Defines: DO NOT MODIFY
// Those defines are used internally to help converting the DEFAULT_HF_CLOCK_SOURCE and DEFAULT_LF_CLOCK_SOURCE
// selection of each clock branch to the right HW register value.
#define SL_CLOCK_MANAGER_DEFAULT_HF_CLOCK_SOURCE_HFRCODPLL    0xFF
#define SL_CLOCK_MANAGER_DEFAULT_HF_CLOCK_SOURCE_HFXO         0xFE
#define SL_CLOCK_MANAGER_DEFAULT_HF_CLOCK_SOURCE_FSRCO        0xFD
#define SL_CLOCK_MANAGER_DEFAULT_LF_CLOCK_SOURCE_LFRCO        0xFC
#define SL_CLOCK_MANAGER_DEFAULT_LF_CLOCK_SOURCE_LFXO         0xFB
#define SL_CLOCK_MANAGER_DEFAULT_LF_CLOCK_SOURCE_ULFRCO       0xFA

#if defined(SL_CATALOG_RAIL_LIB_PRESENT)
#define SL_CLOCK_MANAGER_DEFAULT_HF_CLOCK_SOURCE_AUTO         SL_CLOCK_MANAGER_DEFAULT_HF_CLOCK_SOURCE_HFXO
#else
#define SL_CLOCK_MANAGER_DEFAULT_HF_CLOCK_SOURCE_AUTO         SL_CLOCK_MANAGER_DEFAULT_HF_CLOCK_SOURCE_HFRCODPLL
#endif

// <<< Use Configuration Wizard in Context Menu >>>

// <h> Clock Tree Settings

// <o SL_CLOCK_MANAGER_DEFAULT_HF_CLOCK_SOURCE> Default Clock Source Selection for HF clock branches
//   <SL_CLOCK_MANAGER_DEFAULT_HF_CLOCK_SOURCE_AUTO=> AUTO
//   <SL_CLOCK_MANAGER_DEFAULT_HF_CLOCK_SOURCE_HFRCODPLL=> HFRCODPLL
//   <SL_CLOCK_MANAGER_DEFAULT_HF_CLOCK_SOURCE_HFXO=> HFXO
//   <SL_CLOCK_MANAGER_DEFAULT_HF_CLOCK_SOURCE_FSRCO=> FSRCO
// <i> Selection of the high frequency clock source. HF clock branches can select this value by chosing the DEFAULT_HF value.
// <i> AUTO uses HFXO if a radio is used and HFRCODPLL otherwise
// <d> SL_CLOCK_MANAGER_DEFAULT_HF_CLOCK_SOURCE_AUTO
#ifndef SL_CLOCK_MANAGER_DEFAULT_HF_CLOCK_SOURCE
#define SL_CLOCK_MANAGER_DEFAULT_HF_CLOCK_SOURCE    SL_CLOCK_MANAGER_DEFAULT_HF_CLOCK_SOURCE_HFXO
#endif

// <o SL_CLOCK_MANAGER_DEFAULT_LF_CLOCK_SOURCE> Default Clock Source Selection for LF clock branches
//   <SL_CLOCK_MANAGER_DEFAULT_LF_CLOCK_SOURCE_LFRCO=> LFRCO
//   <SL_CLOCK_MANAGER_DEFAULT_LF_CLOCK_SOURCE_LFXO=> LFXO
//   <SL_CLOCK_MANAGER_DEFAULT_LF_CLOCK_SOURCE_ULFRCO=> ULFRCO
// <i> Selection of the low frequency clock source. LF clock branches can select this value by chosing the DEFAULT_HF value.
// <d> SL_CLOCK_MANAGER_DEFAULT_LF_CLOCK_SOURCE_LFRCO
#ifndef SL_CLOCK_MANAGER_DEFAULT_LF_CLOCK_SOURCE
#define SL_CLOCK_MANAGER_DEFAULT_LF_CLOCK_SOURCE    SL_CLOCK_MANAGER_DEFAULT_LF_CLOCK_SOURCE_LFXO
#endif

// <h> System Clock Branch Settings

// <o SL_CLOCK_MANAGER_SYSCLK_SOURCE> Clock Source Selection for SYSCLK branch
//   <SL_CLOCK_MANAGER_DEFAULT_HF_CLOCK_SOURCE=> DEFAULT_HF
//   <CMU_SYSCLKCTRL_CLKSEL_FSRCO=> FSRCO
//   <CMU_SYSCLKCTRL_CLKSEL_HFRCODPLL=> HFRCODPLL
//   <CMU_SYSCLKCTRL_CLKSEL_HFXO=> HFXO
//   <CMU_SYSCLKCTRL_CLKSEL_CLKIN0=> CLKIN0
// <i> Selection of the Clock source for SYSCLK
// <d> SL_CLOCK_MANAGER_DEFAULT_HF_CLOCK_SOURCE
#ifndef SL_CLOCK_MANAGER_SYSCLK_SOURCE
#define SL_CLOCK_MANAGER_SYSCLK_SOURCE    SL_CLOCK_MANAGER_DEFAULT_HF_CLOCK_SOURCE
#endif
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

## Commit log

2025-10-31 Generate rail_soc_empty project
    The project is created from simplicity_sdk_2025.6.2 version.
    The project is created with copy import mode to export the simplicity
    SDK files which makes easier to humans to use VS code workspace
    for all code in the project. This way the AI agents can search in SDK
    code as well.
    The SDK files are not committed because those can be generated
    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
2025-12-17 Add hcs300 timer irq-based processing
2025-12-17 Add mcu, hcs300, board docs
2026-08-14 Add e07-433m20s_board v1.0 board
    [e07-433m20s_board.kicad_pcb, e07-433m20s_board.kicad_sch]
2026-08-14 Add kee_smart_opener v1.0 board
    [kee_smart_opener.kicad_pcb, kee_smart_opener.kicad_sch]
2026-08-24 Extend kso-fw with basic led and button support
2026-10-11 Add cc1101 basic tests
    The studiofuga/cc1101 repo is forked to fix some issues and to modify
    initialization to enable HCS300 packet format transmission tests.
    The original cc1101 repo is replaced with the forked one in west.yml.
    The cc1101 is added to devicetree and test code is enable the LDO and to
    control TX/RX pins of e07-433m20s radio module (with cc1101).
    The tranmission of valid HCS300 KeeLoq packets is verified with
    rtl_433-rtlsdr program.
